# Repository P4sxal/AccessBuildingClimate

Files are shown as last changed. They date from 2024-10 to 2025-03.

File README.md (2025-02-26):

This repo contains everything to build a system for monitoring temperature and humidity in a building.
Dedicated sensors are built to measure and send the data via Http API to a host server.
The collected data is stored and visualized with a web interface.

## Sensor design

The Sensor is based on the SHT30 IC from Sensiron, a digital temperature and humidity sensor.
https://sensirion.com/products/catalog/SHT30-DIS-B

A custom PCB was designed to read the sensor from a raspberry zero w.

SHT30 dongle:

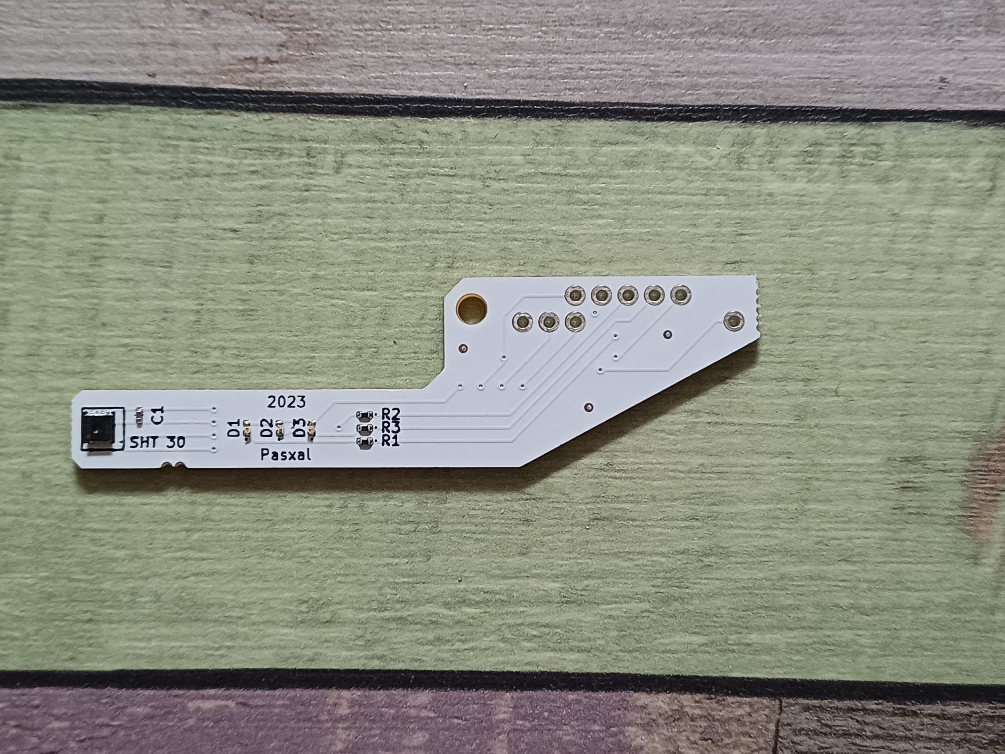
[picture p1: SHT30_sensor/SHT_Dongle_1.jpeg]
SHT30Dongle

CAD view
eCAD view

## Sensor Software

The sensor is read via the I2C bus using a python script.  
The dongle features 3 status LED (red, green and orange).  
A systemd service and timer unit are logging the data as a separated, dedicated system user (mydongle).  
Data is written to a sambda drive, then copyed to local NAS an visualized using a webserver (other project).

## Usage

Copy `SHT30_software` and `setup.sh` to your Raspberry with attached dongle.  
Run `chmod +X setup.sh`, then `sudo ./setup.sh` to finish installation.
The device will start logging climatic data.  
Verify the running service:  
`systemctl status mydongle.service` or `systemctl status mydongle.timer`  

```
{"time": "Mon Feb 24 11:22:41 2025", "temperature": 14.16, "humidity": 59.68, "timestamp": 1740392561.3886838, "hostname": "cellar"}
```
That's it.

---
written by P4sxal 2024-2025

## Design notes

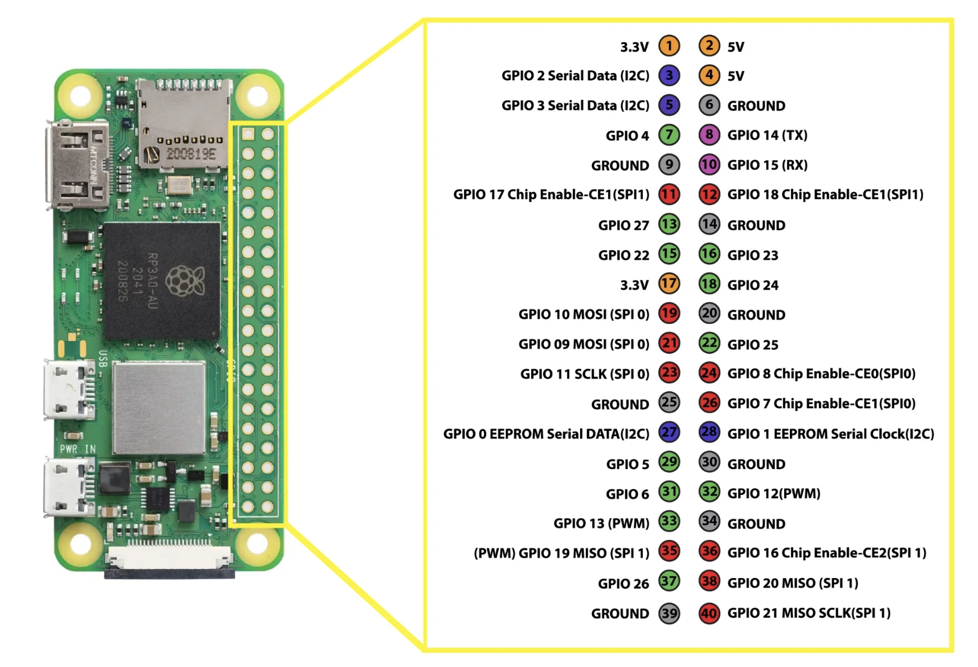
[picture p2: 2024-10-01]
SHT30_sensor/pinout.png

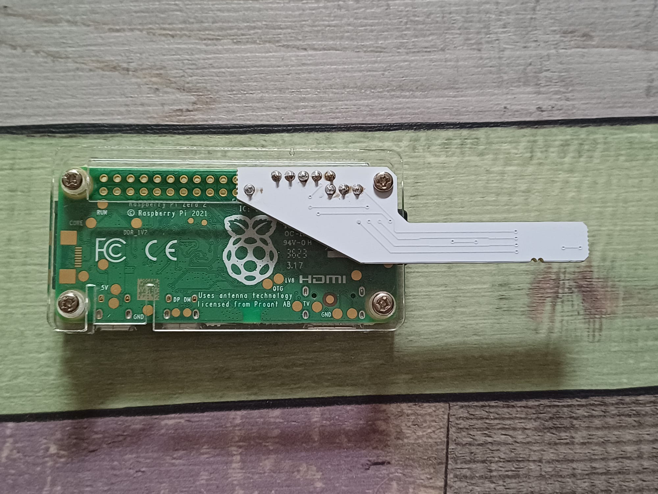
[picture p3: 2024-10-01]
SHT30_sensor/SHT_Dongle_2.jpeg

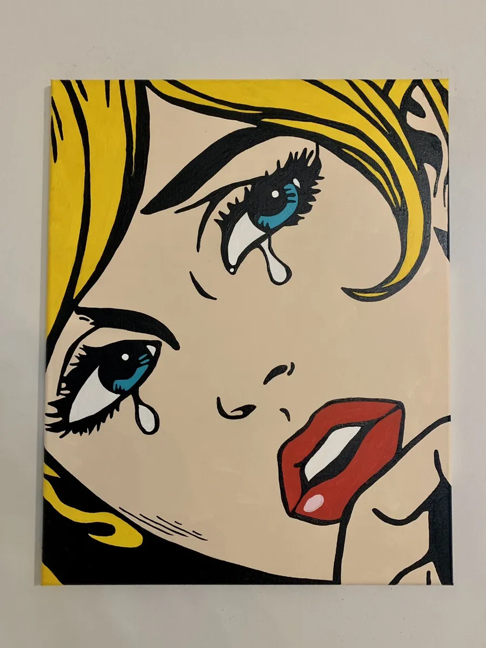
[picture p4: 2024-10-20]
SHT30_software/dontCry.webp

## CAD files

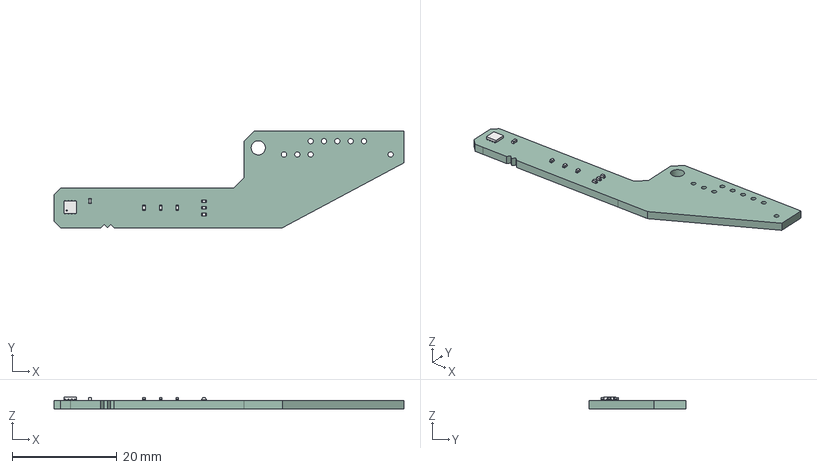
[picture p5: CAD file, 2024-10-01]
SHT30_sensor/sht30_dongle.FCStd
66.7 x 18.4 x 2.23 mm
sht30_dongle PCB

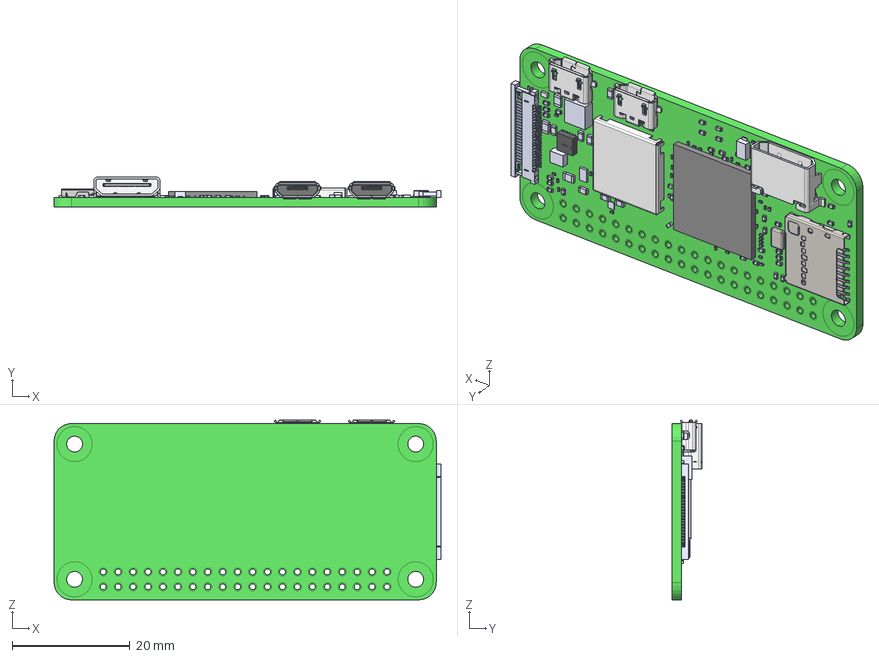
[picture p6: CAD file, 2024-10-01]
SHT30_sensor/raspzero2w.FCStd
65.8 x 5.05 x 30.6 mm
PCB, Raspberry Pi Zero 2 W
RP3A0-AU 2105 201221C, Raspberry Pi Zero 2 W
MicroUSB Port, Raspberry Pi Zero 2 W
MicroUSB Port, Raspberry Pi Zero 2 W001
MicroUSB Port, Raspberry Pi Zero 2 W002
MicroUSB Port, Raspberry Pi Zero 2 W003
MicroUSB Port, Raspberry Pi Zero 2 W004
MicroUSB Port, Raspberry Pi Zero 2 W005
MicroUSB Port, Raspberry Pi Zero 2 W006
SD Card Slot, Raspberry Pi Zero 2 W
SD Card Slot, Raspberry Pi Zero 2 W001
SD Card Slot, Raspberry Pi Zero 2 W002
SD Card Slot, Raspberry Pi Zero 2 W003
SD Card Slot, Raspberry Pi Zero 2 W004
SD Card Slot, Raspberry Pi Zero 2 W005
SD Card Slot, Raspberry Pi Zero 2 W006
SD Card Slot, Raspberry Pi Zero 2 W007
SD Card Slot, Raspberry Pi Zero 2 W008
SD Card Slot, Raspberry Pi Zero 2 W009
Wireless Module Cover, Raspberry Pi Zero 2 W
Crystal Resonator, Raspberry Pi Zero 2 W
LED, Raspberry Pi Zero 2 W
Diode, Schottky, Raspberry Pi Zero 2 W
54548-2271, 22 Pin FPC Connector, Raspberry Pi Zero 2 W
Mini HDMI Receptacle Port, Raspberry Pi Zero 2 W
PAM2306AYPKE, Switching Voltage Regulators Dual PWM Step-Down 40uA 1A 1.5MHz, Raspberry Pi Zero 2 W
RT9081A-1BGQZA, Fixed LDO Voltage Regulator, 0.8V-5.5Vin, 140mV drop, 1.25Vout, 0.5Aout, Raspberry Pi Zero 2 W_default
RT8088AWSC, IC Reg Buck Prog 3A Sync 15WLCSP, Raspberry Pi Zero 2 W_default
SMD Inductor, Configurable, Raspberry Pi Zero 2 W_L1
SMD Inductor, Configurable, Raspberry Pi Zero 2 W_L2
SMD Capacitor, Configurable, Raspberry Pi Zero 2 W_C1
SMD Capacitor, Configurable, Raspberry Pi Zero 2 W_C002
SMD Capacitor, Configurable, Raspberry Pi Zero 2 W_C003
MicroUSB Port, Raspberry Pi Zero 2 W008
MicroUSB Port, Raspberry Pi Zero 2 W009
MicroUSB Port, Raspberry Pi Zero 2 W010
MicroUSB Port, Raspberry Pi Zero 2 W011
MicroUSB Port, Raspberry Pi Zero 2 W012
MicroUSB Port, Raspberry Pi Zero 2 W013
MicroUSB Port, Raspberry Pi Zero 2 W014
SMD Capacitor, Configurable, Raspberry Pi Zero 2 W_C3
SMD Capacitor, Configurable, Raspberry Pi Zero 2 W_C005
SMD Capacitor, Configurable, Raspberry Pi Zero 2 W_C006
SMD Capacitor, Configurable, Raspberry Pi Zero 2 W_C008
SMD Capacitor, Configurable, Raspberry Pi Zero 2 W_C009
SMD Capacitor, Configurable, Raspberry Pi Zero 2 W_C010
SMD Capacitor, Configurable, Raspberry Pi Zero 2 W_C012
SMD Capacitor, Configurable, Raspberry Pi Zero 2 W_C013
SMD Capacitor, Configurable, Raspberry Pi Zero 2 W_C014
SMD Capacitor, Configurable, Raspberry Pi Zero 2 W_C016
SMD Capacitor, Configurable, Raspberry Pi Zero 2 W_C017
SMD Capacitor, Configurable, Raspberry Pi Zero 2 W_C018
SMD Capacitor, Configurable, Raspberry Pi Zero 2 W_C020
SMD Capacitor, Configurable, Raspberry Pi Zero 2 W_C021
SMD Capacitor, Configurable, Raspberry Pi Zero 2 W_C022
SMD Capacitor, Configurable, Raspberry Pi Zero 2 W_C024
SMD Capacitor, Configurable, Raspberry Pi Zero 2 W_C025
SMD Capacitor, Configurable, Raspberry Pi Zero 2 W_C026
SMD Capacitor, Configurable, Raspberry Pi Zero 2 W_C028
SMD Capacitor, Configurable, Raspberry Pi Zero 2 W_C029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

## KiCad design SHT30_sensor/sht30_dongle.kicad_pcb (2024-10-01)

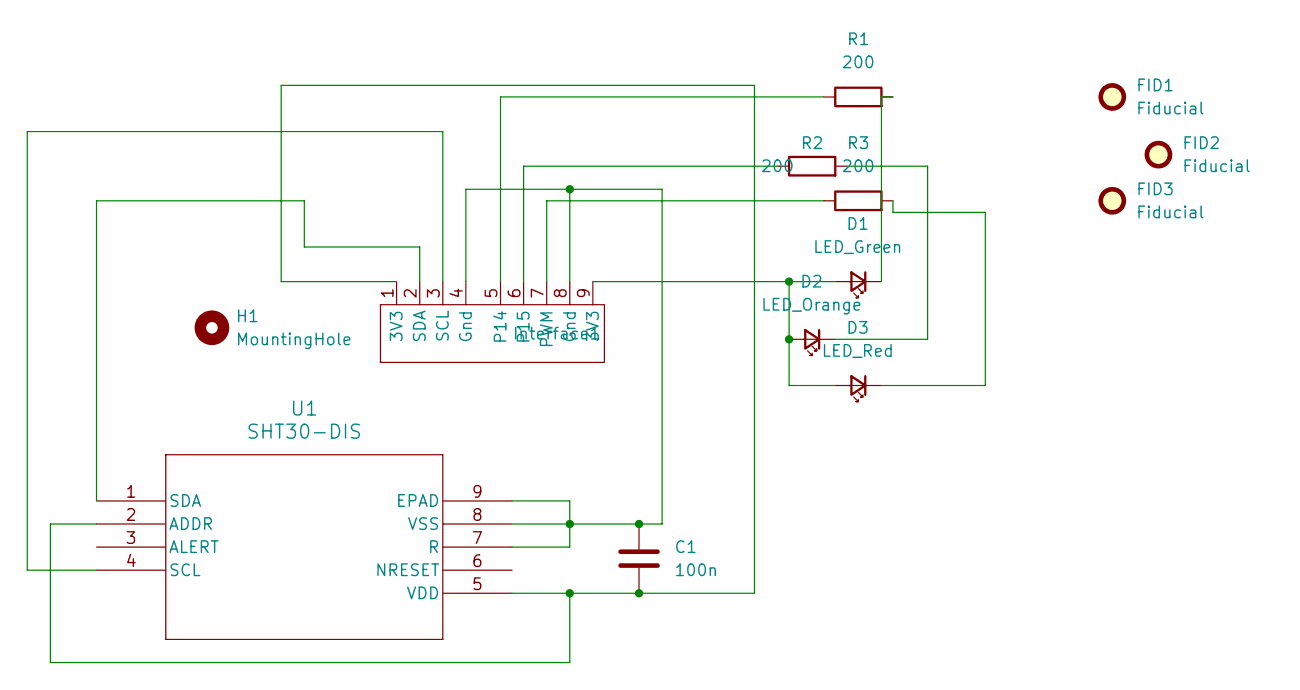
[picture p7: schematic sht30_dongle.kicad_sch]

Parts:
C1: 100n; C_0402_1005Metric
D1: LED_Green; LED_0402_1005Metric
D2: LED_Orange; LED_0402_1005Metric
D3: LED_Red; LED_0402_1005Metric
FID1, FID2, FID3: Fiducial; Fiducial_0.5mm_Mask1mm
H1: MountingHole; MountingHole_2.7mm_M2.5
Interface1: Pi_i2c_interface
R1, R2, R3: 200; LED_0402_1005Metric
U1: SHT30-DIS; SHT3X_DIS_SEN

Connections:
unnamed: D1.2 (A), D2.2 (A), D3.2 (A), Interface1.9 (3V3)
unnamed: D1.1 (K), R1.2
unnamed: D2.1 (K), R2.2
unnamed: D3.1 (K), R3.2
unnamed: Interface1.5 (P14), R1.1
unnamed: Interface1.6 (P15), R2.1
unnamed: Interface1.7 (PWM), R3.1
unnamed: Interface1.3 (SCL), U1.4 (SCL)
unnamed: Interface1.2 (SDA), U1.1 (SDA)
unnamed: C1.2, Interface1.1 (3V3), U1.2 (ADDR), U1.5 (VDD)
unnamed: C1.1, Interface1.4 (Gnd), Interface1.8 (Gnd), U1.7 (R), U1.8 (VSS), U1.9 (EPAD)

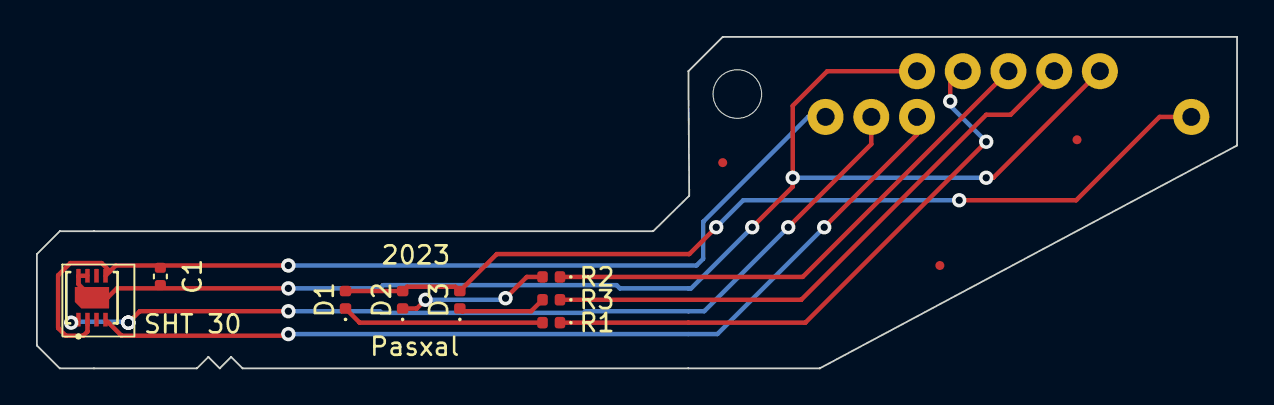
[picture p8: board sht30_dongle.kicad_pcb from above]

Board: 2 copper layers, 66.7 x 18.4 mm, 13 parts (0 on the bottom side), 11 nets.

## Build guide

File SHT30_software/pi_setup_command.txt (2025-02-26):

#Log the temperatures using the SHT30 dongle
#the scripts executes a python script to read the SHT30 dongle each 10

#first, check the shell and python scripts
#can be executed with "./logClimaWithDongle.sh"
#python script: "py dongleSHT30.py"

#crontab, use "crontab -e"
#*/10 * * * * /home/pi/Desktop/readTempHum.sh >/dev/null 2>&1

# ----
# how to install:

# mount a SMB directory for coping files with fstab
# /etc/fstab
# //rose/OfficeLog        /mnt/officelog  cifs    username=rasp8,password=P,uid=pi,gid=pi,_netdev,x-systemd.automount,nofail

#use sftp to transfer files to target device
# put SHT30_Software
# put setup.sh

# change permissions on setup.sh
chmod +x setup.sh

#execute script
sudo ./setup.sh

#-------------------
#-------------------
#-------------------

#create new user
sudo adduser --system mydongle

#copy SHT30_Software and change userrights
sudo cp -r SHT30_software/ /home/mydongle/
sudo chown -R mydongle SHT30_Software

#write the service unit
vi mydongle.service

#copy it to be usable by systemd
sudo cp mydongle.service /etc/systemd/system
sudo systemctl daemon-reload
sudo systemctl enable mydongle.service
sudo systemctl start mydongle.service

## mydongle.service
## -------
[Unit]
Description=Dongle Software
After=network-online.target

[Service]
User=mydongle
Type=exec
ExecStart= /usr/bin/python3 /home/mydongle/SHT30_software/dongleSHT30.py
StandardOutput=append:/home/mydongle/log11.log
#StandardError=journal
Restart=no

[Install]
WantedBy=default.target
## -------

## -------
## mydongle.timer
pi@raspberryzero4:~/Desktop $ less mydongle.timer 

[Unit]
Description= "timer for logging mydongle"

[Timer]
#OnBootSec=5min
OnUnitActiveSec=9min
#OnCalendar=Mon..Fri *-*-* *:03:*
Unit=mydongle.service

[Install]
WantedBy=multi-user.target
## ------

#to access the gpio of raspberry, add user to group
# Error: "RuntimeError: No access to /dev/mem" from gpio
# more Error: "self._bus = smbus.SMBus(smbus_adress)
#                ^^^^^^^^^^^^^^^^^^^^^^^^^
# PermissionError: [Errno 13] Permission denied
sudo adduser mydongle gpio i2c

#now lets write a timer for each x min
sudo cp mydongle.timer /etc/systemd/system
sudo systemctl enable mydongle.timer
sudo systemctl start mydongle.timer

#lets observe the logs

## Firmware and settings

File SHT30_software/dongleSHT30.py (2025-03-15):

#SHT30_Dongle_LEDs

# The dongle has three built in LEDs, green, yellow and red.
# pin 14 is green, 15 is yellow and 18 is red, mapped to raspberry zero pin naming
# pull to ground to switch on the led

#gpio interface for raspberry
from gpiozero import LED
#smbus to interface the SHT30 via I2C
import smbus
from time import sleep, ctime, time
#creating a timestamp + hostname
from os import uname, environ
import json

#which dongle can be selected by args
import argparse

parser = argparse.ArgumentParser(description='''SHT30dongle interface''')
parser.add_argument("-st",dest="sensortype",default="wired",help="'wired' or 'dongle', default 'wired'")
#parser.add_argument("-dst")
parser.add_argument("-loc",default="unknown")
args=parser.parse_args()

# define the colors
class SHT30_dongle():
    """
    Represents the dedicated Dongle with SHT30 Sensor and 3 LEDs for RPi zero

    The device is compatible to standard RPi zero, thus can be soldered without wires.
    The physical data can be found in the SHT30_sensor folder.
    Included are CAE, CAD and gerber files. 
    SHT30 address, 0x45(68), per default.
    """
    def __init__(self,smbus_adress = 1):
        
        if args.sensortype == 'wired':
            __i2c_address = 0x45
        elif args.sensortype == 'dongle':
            __i2c_address = 0x44
        else:
            raise Exception("Sensortype not found")
        
        self._green = LED(14, active_high = False)
        self._yellow = LED(15, active_high = False)
        self._red = LED(18, active_high = False)
        self._bus = smbus.SMBus(smbus_adress)
        self._i2c_address = __i2c_address
        self._update_temp_hum()
            
    def log_clima(self):
        #post the clim data in json format
        self._update_temp_hum()
        temp = self._temp
        hum = self._hum
        stringtime = ctime()
        timestamp = time()
        hostname = uname()[1]
        return json.dumps({
            "time":stringtime,
            "temperature":temp,
            "humidity":hum,
            "timestamp":timestamp,
            "location":args.loc,
            "hostname":hostname
        })
    
    def log_clima_dict(self):
        #post the clim data in json format
        self._update_temp_hum()
        temp = self._temp
        hum = self._hum
        stringtime = ctime()
        timestamp = time()
        hostname = uname()[1]
        return {
            "time":stringtime,
            "temperature":temp,
            "humidity":hum,
            "timestamp":timestamp,
            "location":args.loc,
            "hostname":hostname
        }

    def _update_temp_hum(self):
        # reads the temp and hum from the SHT30 dongle
        try:
            # Send measurement command, 0x2C
            # 0x06(06) High repeatability measurement
            self._bus.write_i2c_block_data(self._i2c_address, 0x2C, [0x06])
            sleep(0.5)
            # Read data back from 0x00(00), 6 bytes
            # cTemp MSB, cTemp LSB, cTemp CRC, Humididty MSB, Humidity LSB, Humidity CRC
            data = self._bus.read_i2c_block_data(self._i2c_address, 0x00, 6)
            # Convert the data
            cTemp = round(((((data[0] * 256.0) + data[1]) * 175) / 65535.0) - 45, 2)
            humidity = round(100 * (data[3] * 256 + data[4]) / 65535.0, 2)
            self._temp, self._hum = cTemp,humidity
        except:
            raise Exception("Could not read the dongle, is it attached?")

    @property
    def temperature(self):
        self._update_temp_hum()
        return self._temp
    
    @property
    def humidity(self):
        self._update_temp_hum()
        return self._hum

    def led_on(self):
        self._green.on()
        self._yellow.on()
        self._red.on()

    def led_off(self):
        self._green.off()
        self._yellow.off()
        self._red.off()
        
    def led_blink(self):
        self._green.off()
        self._yellow.off()
        self._red.on()
        sleep(1.0)
        self._yellow.on()
        self._green.off()
        self._red.off()
        sleep(1.0)
        self._yellow.off()
        self._green.on()
        self._red.off()
        sleep(1.0)

if __name__ == "__main__":
    sensor=SHT30_dongle()
    sensor.led_blink()
    #with open(args.loc+".txt","a") as file: 
    #    file.write(sensor.log_clima())

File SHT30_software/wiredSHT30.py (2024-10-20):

# Distributed with a free-will license.
# Use it any way you want, profit or free, provided it fits in the licenses of its associated works.
# SHT30
# This code is designed to work with the SHT30_I2CS I2C Mini Module available from ControlEverything.com.
# https://www.controleverything.com/content/Humidity?sku=SHT30_I2CS#tabs-0-product_tabset-2

import smbus
import time
from os import uname

# Get I2C bus
bus = smbus.SMBus(1)

# SHT30 address, 0x44(68)
# Send measurement command, 0x2C(44)
#		0x06(06)	High repeatability measurement
bus.write_i2c_block_data(0x44, 0x2C, [0x06])

time.sleep(0.5)

# SHT30 address, 0x44(68)
# Read data back from 0x00(00), 6 bytes
# cTemp MSB, cTemp LSB, cTemp CRC, Humididty MSB, Humidity LSB, Humidity CRC
data = bus.read_i2c_block_data(0x44, 0x00, 6)

# Convert the data
cTemp = round(((((data[0] * 256.0) + data[1]) * 175) / 65535.0) - 45, 2)
humidity = round(100 * (data[3] * 256 + data[4]) / 65535.0, 2)

print(f"{uname()[1]},{time.ctime()},{time.time()},{cTemp},{humidity}")

# Output data to screen
#print(f"Relative Humidity : {humidity}")
#print(f"Temperature in Celsius : {cTemp}")

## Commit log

2024-10-20 start cleaning
    [raspzero2w.FCStd, sht30_dongle.FCStd, sht30_dongle.kicad_pcb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]
2025-02-15 systemd service and timer written
2025-02-26 systemd service and timer added and tested successfully
